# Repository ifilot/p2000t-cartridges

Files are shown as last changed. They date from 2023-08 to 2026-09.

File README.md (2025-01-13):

# P2000T Cartridges



## Purpose
Set of homebrew multirom cartridges for the P2000T. These cartridges contain
multiple ROM files stored on a single parallel EEPROM chip. The user can select
the desired program using a DIP switch. More information on these cartridges can
be found [on the website](https://www.philips-p2000t.nl/).

> [!TIP] 
> Have questions or comments about the **P2000T Cartridges**? Join
> the conversation and chat with the developers on our [Discord
> server](https://discord.gg/YtzJTWYAxy).

## MultiROM cartridges

> [!TIP]
> * Unsure which cartridge is right for you? The 32x16KiB THT SST39SF040 
>   (512 KiB ROM) offers the most features and is relatively straightforward to 
>   assemble with soldering.
> * When ordering the cartridges, it is advisable to choose an ENIG finish, 
>   opt for gold fingers, and specify a 30-degree chamfer on the edge connector.
> * For flashing the SST39SF0x0 chips, there is [a cheap Flasher tool](https://github.com/ifilot/pico-sst39sf0x0-programmer)
    available, based on the Raspberry Pi PICO.
> * A premade set of cartridge ROM-packs can be found [here](https://github.com/ifilot/p2000t-rompacks).

### 32x16KiB THT SST39SF040 (512 KiB ROM)

A SLOT1 cartridge designed to enable selection from 32 memory banks, assuming
the use of a 512KB ROM chip. It features a dedicated bracket PCB for holding the
DIP switch, which can be connected to the main PCB using either six wires or a
custom flex cable. Additionally, this cartridge includes a soft reset switch,
equipped with a debouncing circuit using a 74HC123 multivibrator. This cartridge
uses **THT** components.

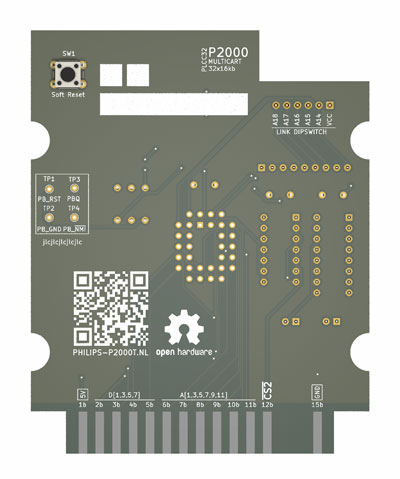
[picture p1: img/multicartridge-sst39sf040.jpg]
P2000T 32x16KiB THT SST39SF040 Cartridge


* [PCB - Multicartridge](multicartridge-tht-top-dipswitch/pcb)
* [PCB - DIP switch plate](multicartridge-tht-top-dipswitch/pcb/dipswitch-plate)
* [Flexcable](multicartridge-tht-top-dipswitch/pcb/flexconnector)
* [Casing (3d-print files)](multicartridge/case)

### 32x16KiB SMD SST39SF040 (512 KiB ROM)

Similar to the 32x16KiB THT SST39SF040 cartridge, this version utilizes **SMD**
components, with the exception of the PLCC32 THT socket used for the SST39SF040
chip. Design schematics for the DIP switch plate and the flexcable can be found
under the `THT` variant. Position and BOM files are provided for assembly
service.

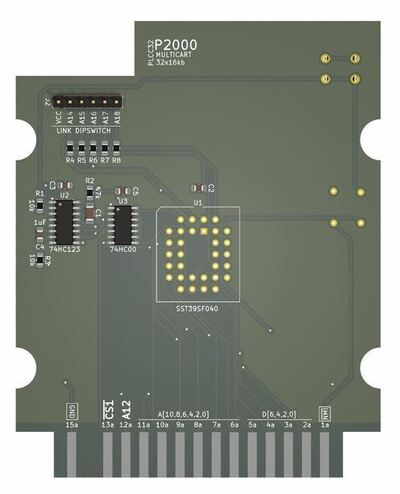
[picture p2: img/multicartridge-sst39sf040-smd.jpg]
P2000T 32x16KiB SMD SST39SF040 Cartridge


* [PCB - Multicartridge](multicartridge-smd-top-dipswitch/pcb)
* [PCB - DIP switch plate](multicartridge-tht-top-dipswitch/pcb/dipswitch-plate)
* [Flexcable](multicartridge-tht-top-dipswitch/pcb/flexconnector)
* [Casing (3d-print files)](multicartridge/case)

### 4 x 16KiB THT W27C512 (64 KiB ROM)

There is also a MultiROM cartridge featuring the reliable W27C512 chip, offering
4x16KB of storage. Unlike the 512KB version, this cartridge omits the soft reset
functionality as a cost-saving measure.

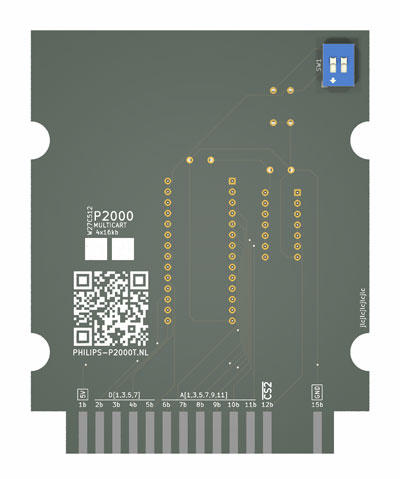
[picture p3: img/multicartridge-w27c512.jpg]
P2000T 4 x 16KiB THT W27C512 Cartridge


* [PCB - Multicartridge](multicartridge-w27c512/pcb)
* [Casing (3d-print files)](multicartridge-w27c512/case)

### Multirom cartridge - ZIF

SLOT1 cartridge that allows the user to select one of 32 banks (assuming a 512kb
ROM chip is used). Instead of a fixed ROM chip, this cartridge uses a ZIF socket
for easy exchange of the ROM chip. The cartridge also contains a soft reset
switch.

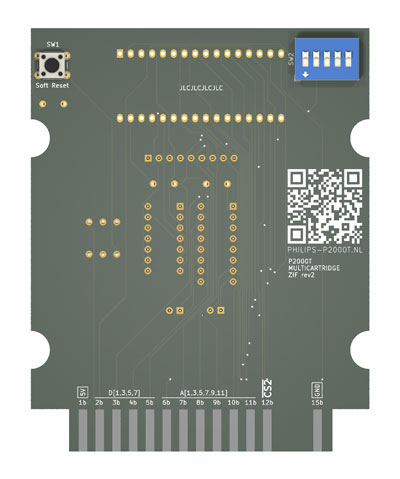
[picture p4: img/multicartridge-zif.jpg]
P2000T Multirom cartridge ZIF


* [PCB](multicartridge-zif/pcb/p2000t-multicartridge-zif)
* [Casing (3d-print files)](multicartridge-zif/case)

### MultiROM cartridge kit (smd)

Simplified version of the SST39SF040 / 512kb cartridge meant for easy soldering.
This cartridge assumes that the SMD components are already placed using an
assembly service of the PCB manufacturer.

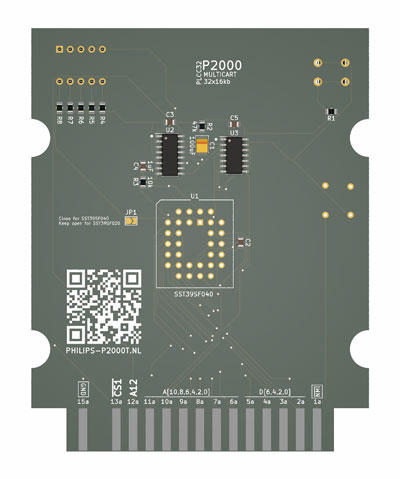
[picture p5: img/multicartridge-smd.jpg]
P2000T MultiROM cartridge kit


* [PCB](multicartridge-smd/pcb)
* [Casing (3d-print files)](multicartridge-smd/case)

## Enclosures

All enclosures have so-called mouse ears which helps in the adhesion
of the enclosure to the print plate. This prevents warping.

Recommended print settings for the enclosures:
* 0.4mm nozzle
* 0.20 - 0.25mm layer height
* 10%-20% infill

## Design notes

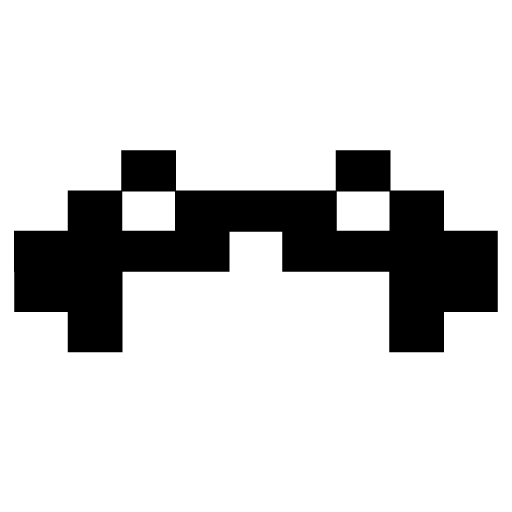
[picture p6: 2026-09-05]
multicartridge-sst39sf010-topbutton/img/fraxxon-goblin-shooter.png

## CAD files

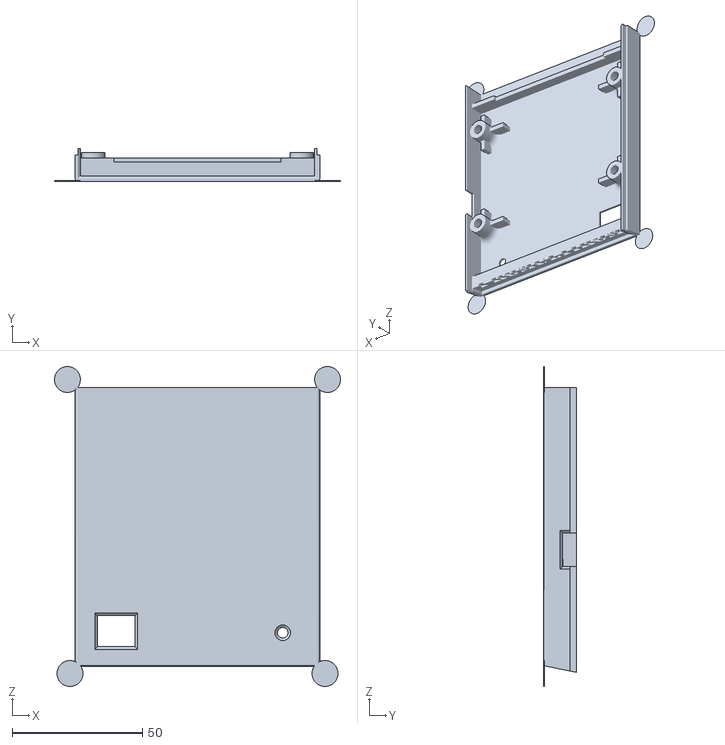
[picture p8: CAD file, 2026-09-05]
multicartridge-smd-32u4-front-dipswitch/case/multicolor/top.stl
110.0 x 12.5 x 123.0

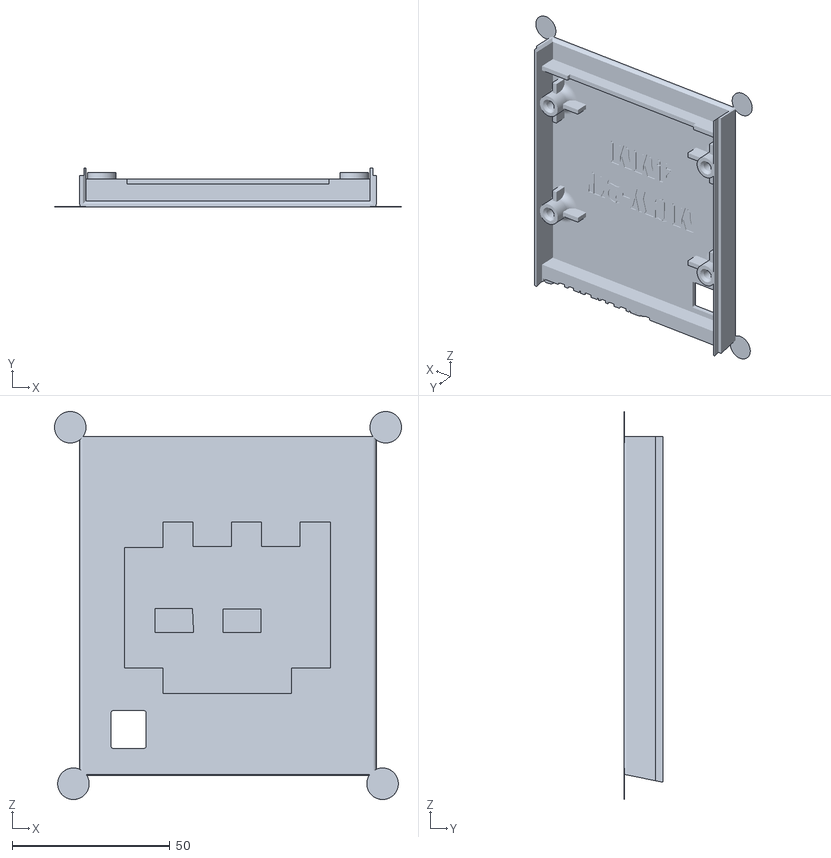
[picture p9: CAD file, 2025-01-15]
multicartridge-sst39sf010/cases/p2000t_gamecartridge_top.stl
110.0 x 12.5 x 123.0

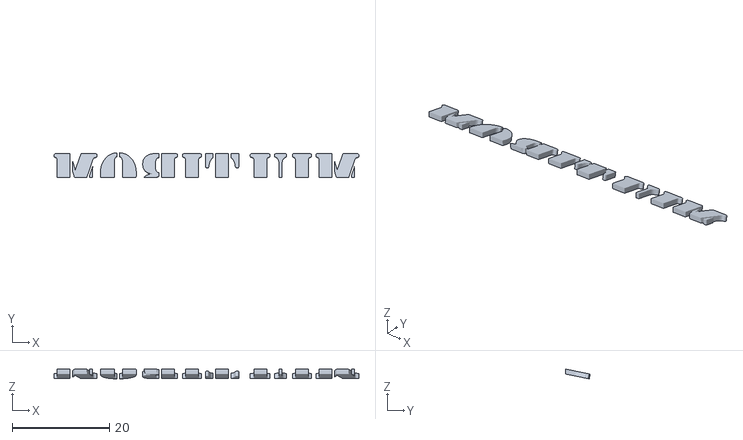
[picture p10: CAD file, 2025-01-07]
multicartridge-tht-top-dipswitch/case/multimaterial/p2000t_multicartridge-label-03-bottom.stl
62.6 x 5.04 x 2.01

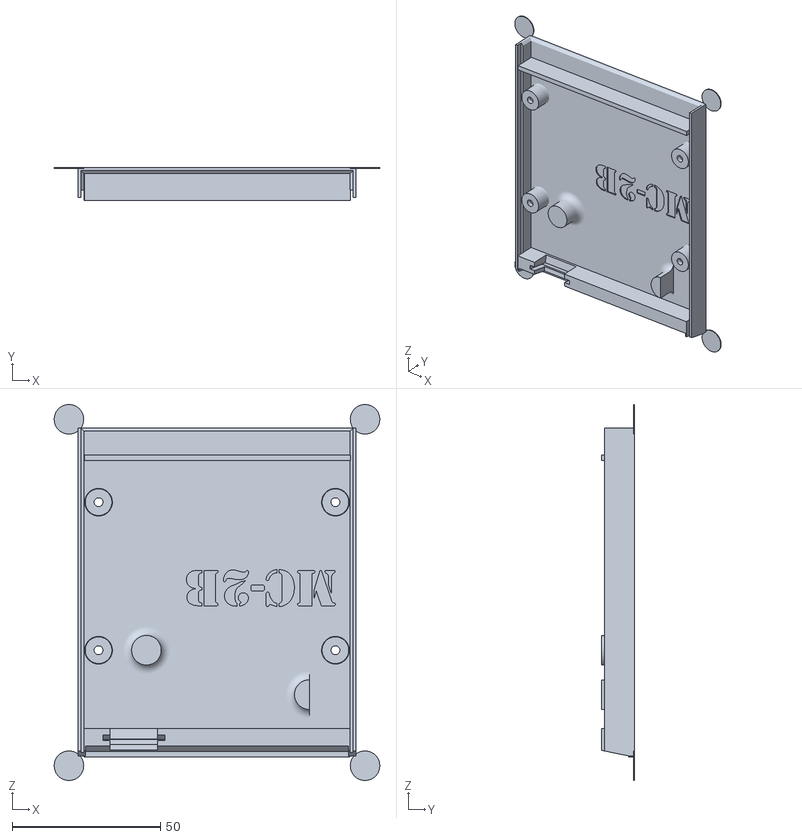
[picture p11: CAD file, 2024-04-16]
multicartridge-tht-top-dipswitch/case/p2000t_multicartridge_bottom.stl
110.0 x 11.0 x 127.0

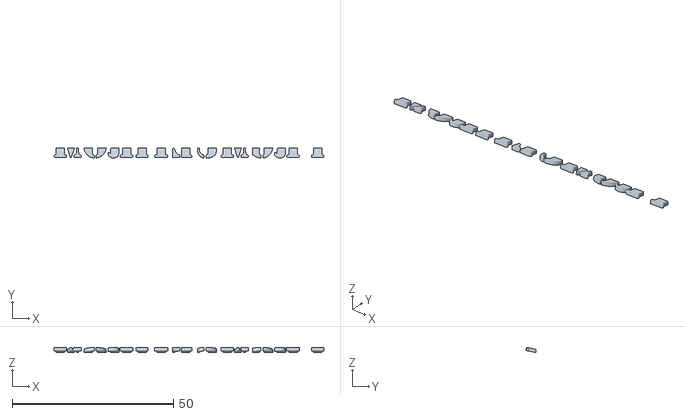
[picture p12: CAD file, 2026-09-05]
multicartridge-smd-32u4-front-dipswitch/case/multicolor/label-top.stl
83.7 x 3.14 x 1.62

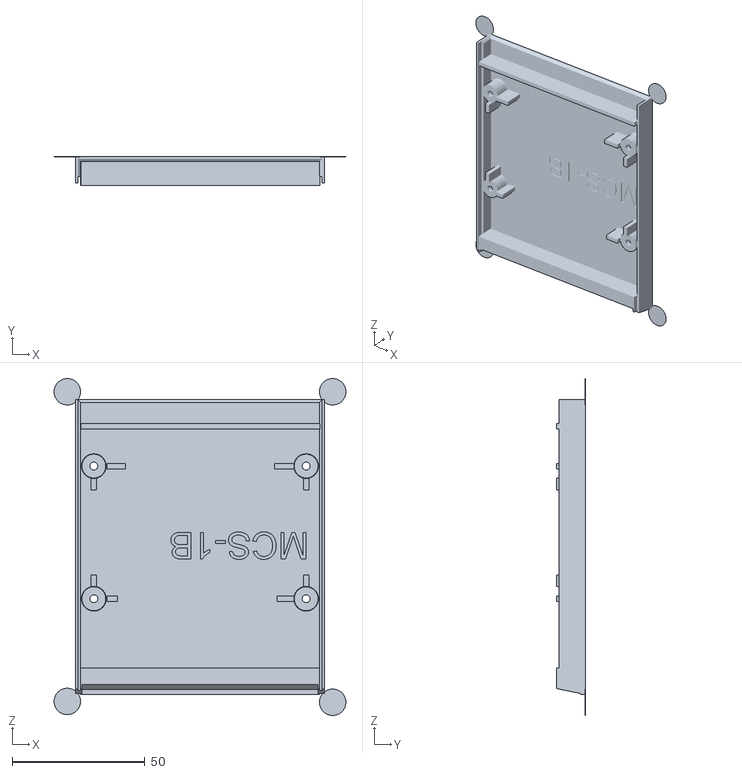
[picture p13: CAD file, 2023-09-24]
multicartridge-smd/cases/p2000t-smd-bottom.stl
110.0 x 11.0 x 127.0

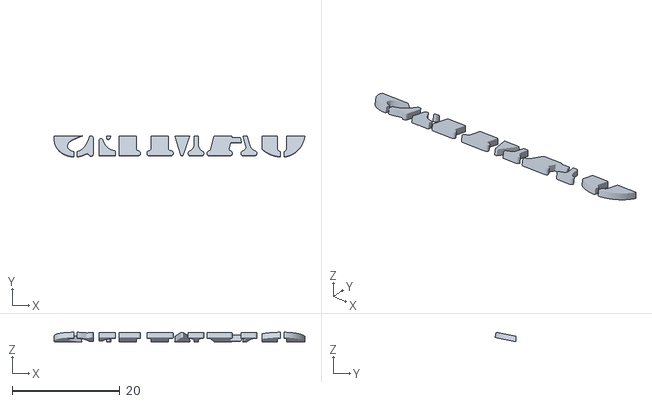
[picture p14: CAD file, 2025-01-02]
multicartridge-sst39sf010/cases/p2000t_gamecartridge_label_top.stl
46.6 x 3.93 x 1.78

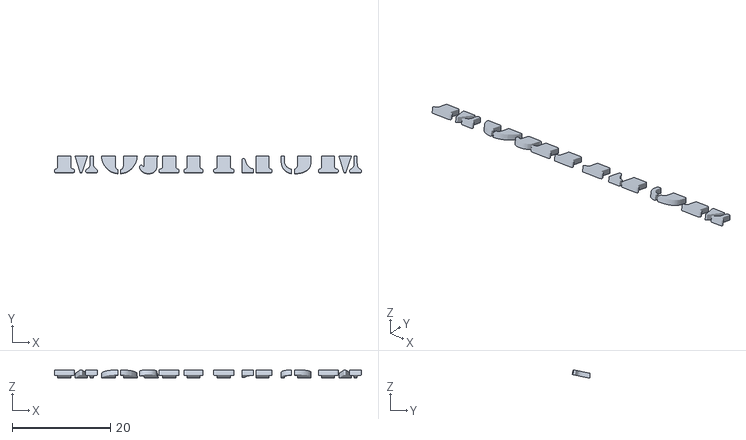
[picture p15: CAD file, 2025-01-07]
multicartridge-tht-top-dipswitch/case/multimaterial/p2000t_multicartridge-label-03-top.stl
62.5 x 3.62 x 1.72

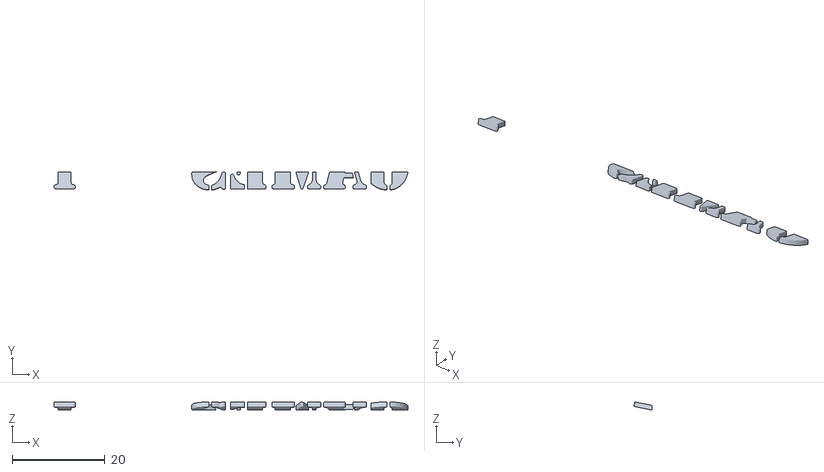
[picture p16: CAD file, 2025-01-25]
multicartridge-w27c512/cases/multimaterial/p2000t_gamecartridge_w27c512_label_top.stl
76.3 x 3.93 x 1.78

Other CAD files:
multicartridge-smd-32u4-front-dipswitch/case/top-bare.stl
multicartridge-smd/cases/p2000t-smd-top.stl
multicartridge-w27c512/cases/multicartridge_w27c512_bottom.stl
multicartridge-w27c512/cases/multimaterial/p2000t_gamecartridge_w27c512_top.stl
multicartridge-zif/case/p2000t_cartridge_zif_top_insert_38.stl
multicartridge-smd-32u4-front-dipswitch/case/bottom-bare.stl
multicartridge-tht-top-dipswitch/case/p2000t_multicartridge_top.stl
multicartridge-w27c512/cases/multicartridge_w27c512_top_4mm_inserts.stl
multicartridge-zif/case/p2000t_cartridge_zif_top.stl
multicartridge-smd-32u4-front-dipswitch/case/multicolor/bottom.stl
multicartridge-smd-32u4-front-dipswitch/case/multicolor/label-bottom.stl
multicartridge-sst39sf010/cases/p2000t_gamecartridge_bottom.stl
multicartridge-sst39sf010/cases/p2000t_gamecartridge_ghost.stl
multicartridge-sst39sf010/cases/p2000t_gamecartridge_label_bottom.stl
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

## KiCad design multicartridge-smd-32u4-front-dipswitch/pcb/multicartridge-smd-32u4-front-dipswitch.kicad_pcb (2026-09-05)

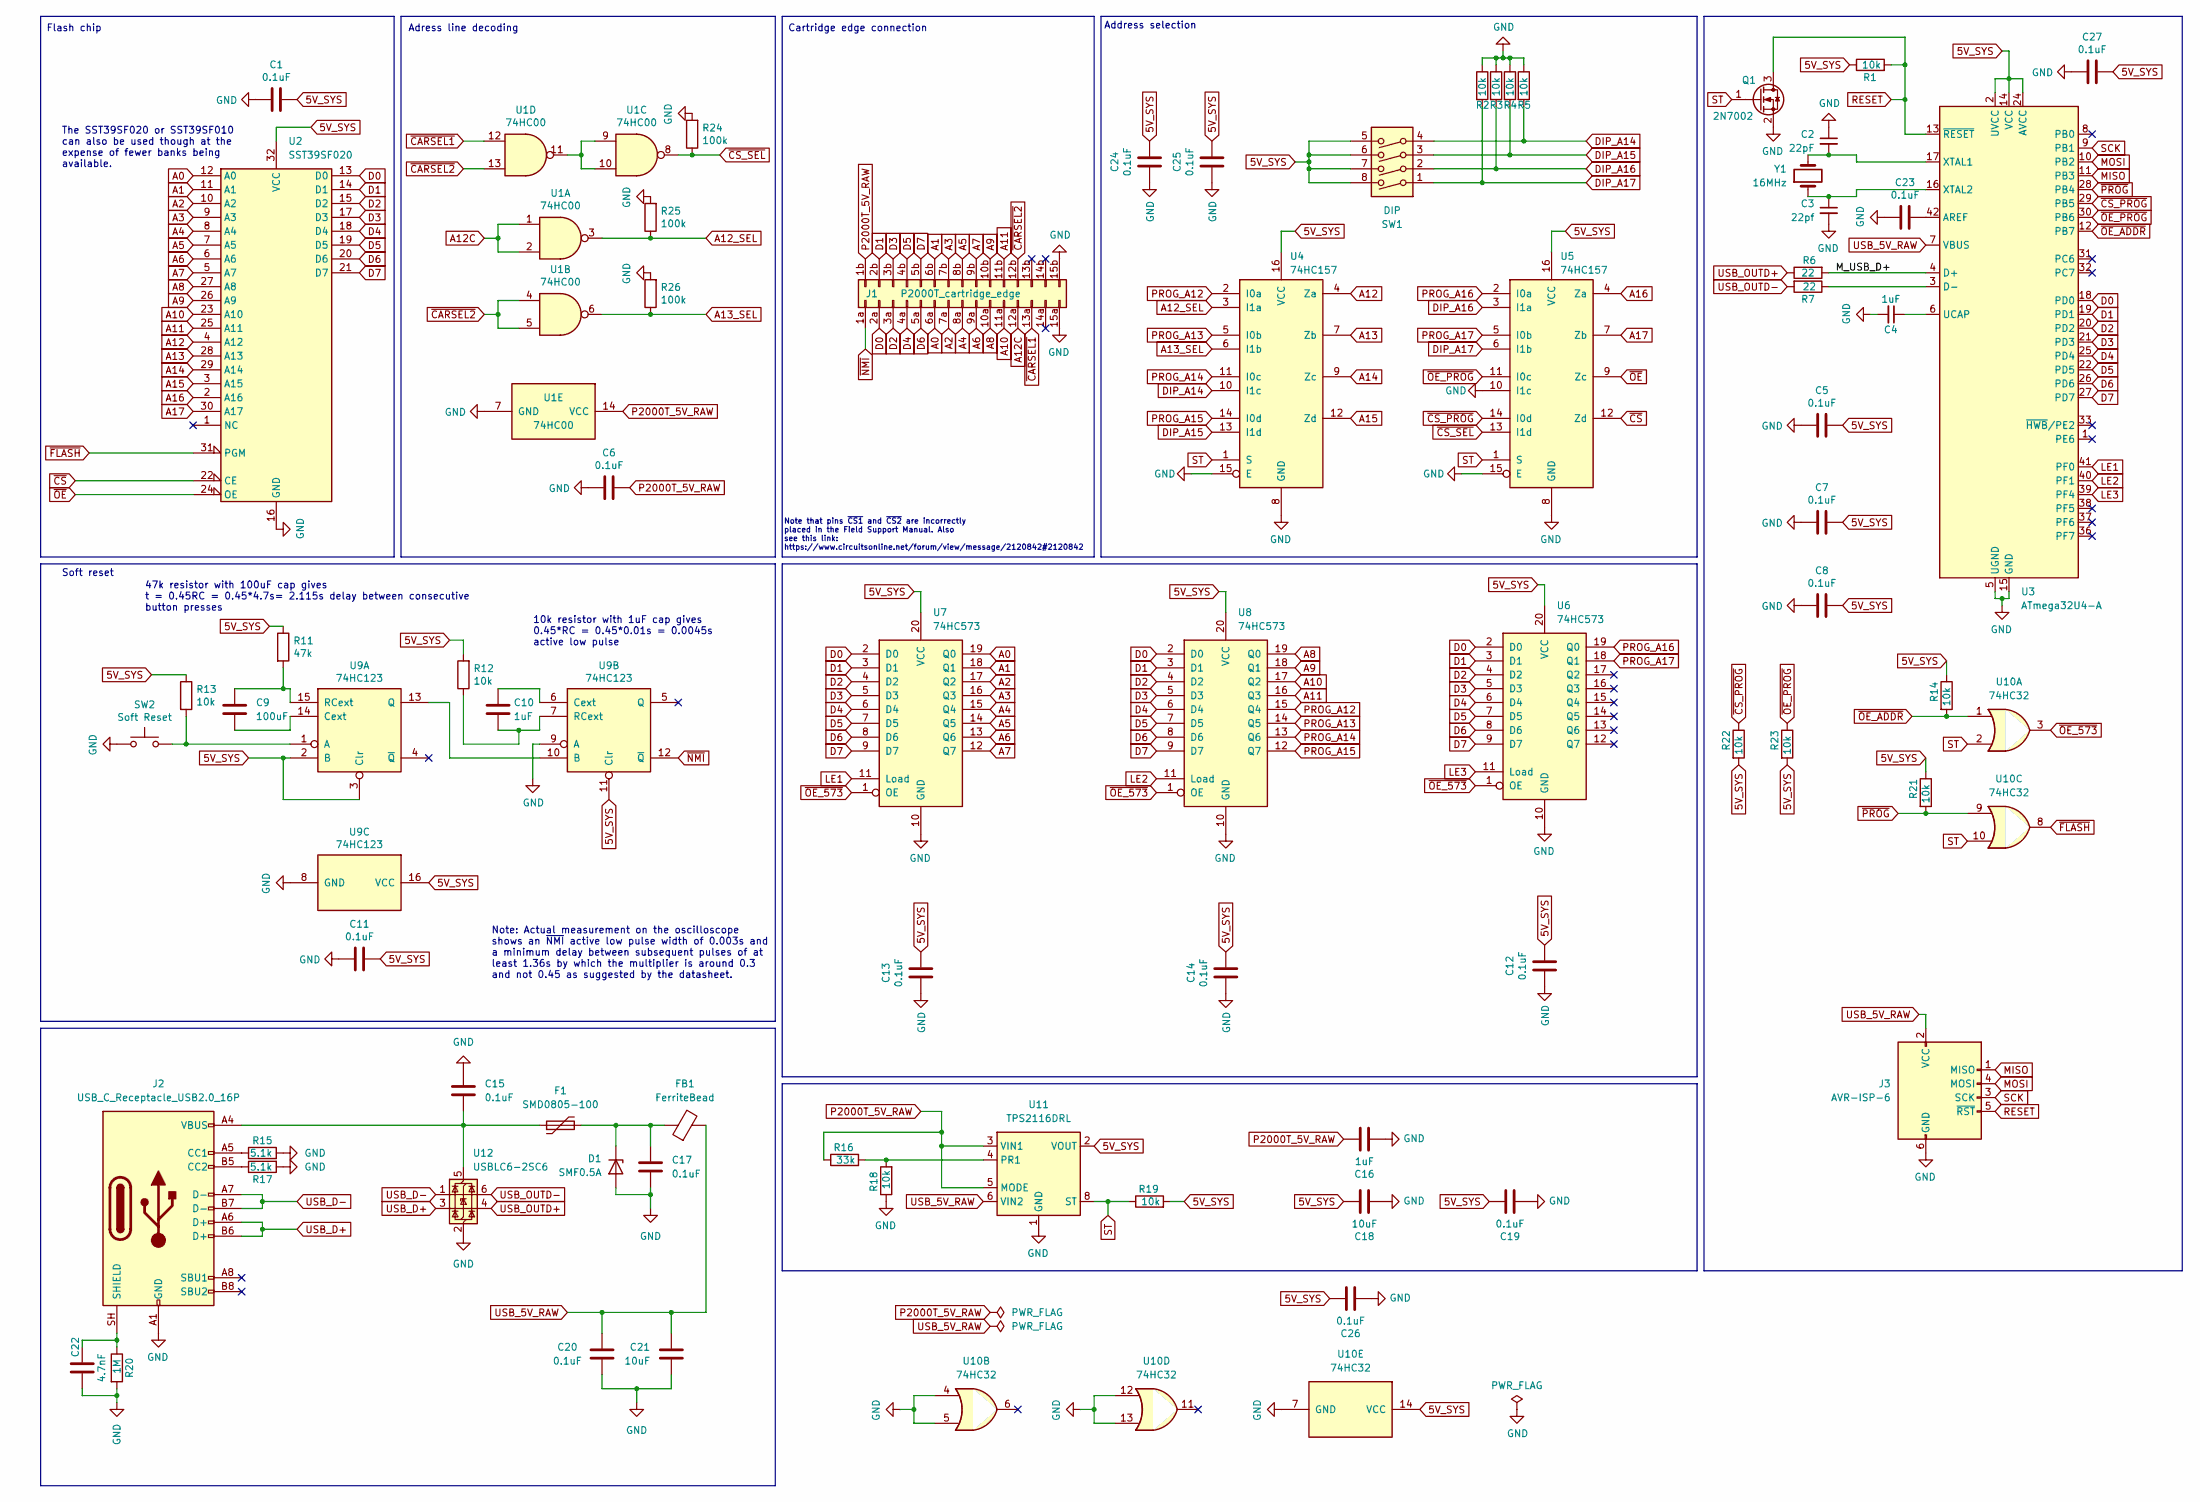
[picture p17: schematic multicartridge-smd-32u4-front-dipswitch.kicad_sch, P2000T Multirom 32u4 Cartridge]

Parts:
C1, C5, C6, C7, C8, C11, C12, C13, C14, C15, C17, C19, C20, C23, C24, C25, C26, C27: 0.1uF; C_0805_2012Metric; LCSC C28233
C2: 22pF; C_0805_2012Metric; LCSC C1804
C3: 22pf; C_0805_2012Metric; LCSC C1804
C4, C10, C16: 1uF; C_0805_2012Metric; LCSC C28323
C9: 100uF; C_1206_3216Metric; LCSC C15008
C18, C21: 10uF; C_0805_2012Metric; LCSC C15850
C22: 4.7nF; C_0805_2012Metric; LCSC C1744
D1: SMF0.5A; D_SOD-123F; LCSC C20883113
F1: SMD0805-100; Fuse_0805_2012Metric; LCSC C22435710
FB1: FerriteBead; R_0805_2012Metric; LCSC C1015
J1: P2000T_cartridge_edge; p2000t_cartridge_edge
J2: USB_C_Receptacle_USB2.0_16P; USB_C_Receptacle_HRO_TYPE-C-31-M-12
J3: AVR-ISP-6; IDC-Header_2x03_P2.54mm_Vertical
Q1: 2N7002; SOT-23; LCSC C8545
R1, R2, R3, R4, R5, R12, R13, R14, R18, R19, R21, R22, R23: 10k; C_0805_2012Metric; LCSC C17414
R6, R7: 22; R_0805_2012Metric; LCSC C17561
R11: 47k; C_0805_2012Metric; LCSC C17713
R15, R17: 5.1k; R_0805_2012Metric; LCSC C27834
R16: 33k; C_0805_2012Metric; LCSC C17633
R20: 1M; R_0805_2012Metric; LCSC C27834
R24, R25, R26: 100k; C_0805_2012Metric; LCSC C17514
SW1: DIP; SW_DIP_SPSTx04_Slide_9.78x12.34mm_W7.62mm_P2.54mm
SW2: Soft Reset; SW_PUSH_6mm
U1: 74HC00; SOIC-14_3.9x8.7mm_P1.27mm; LCSC C5586
U2: SST39SF020; PLCC-32_THT-Socket
U3: ATmega32U4-A; TQFP-44_10x10mm_P0.8mm; LCSC C44854
U4, U5: 74HC157; SOIC-16_3.9x9.9mm_P1.27mm; LCSC C5609
U6, U7, U8: 74HC573; SOIC-20W_7.5x12.8mm_P1.27mm; LCSC C5608
U9: 74HC123; SOIC-16_3.9x9.9mm_P1.27mm; LCSC C5597
U10: 74HC32; SOIC-14_3.9x8.7mm_P1.27mm; LCSC C5632
U11: TPS2116DRL; SOT-583-8; LCSC C3235557
U12: USBLC6-2SC6; SOT-23-6; LCSC C2687116
Y1: 16MHz; Crystal_HC49-U_Vertical

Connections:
5V_SYS: C1.1, C5.1, C7.1, C8.1, C11.1, C12.1, C13.1, C14.1, C18.1, C19.1, C24.1, C25.1, C26.1, C27.1, R1.1, R11.1, R12.2, R13.1, R14.1, R19.2, R21.1, R22.2, R23.2, SW1.5, SW1.6, SW1.7, SW1.8, U2.32 (VCC), U3.2 (UVCC), U3.14 (VCC), U3.24 (AVCC), U3.34 (VCC), U3.44 (AVCC), U4.16 (VCC), U5.16 (VCC), U6.20 (VCC), U7.20 (VCC), U8.20 (VCC), U9.2 (B), U9.3 (Clr), U9.11 (Clr), U9.16 (VCC), U10.14 (VCC), U11.2 (VOUT), U11.7 (VOUT)
/M_USB_D+: R6.2, U3.4 (D+)
A0: J1.6a, U2.12 (A0), U7.19 (Q0)
A1: J1.6b, U2.11 (A1), U7.18 (Q1)
A2: J1.7a, U2.10 (A2), U7.17 (Q2)
A3: J1.7b, U2.9 (A3), U7.16 (Q3)
A4: J1.8a, U2.8 (A4), U7.15 (Q4)
A5: J1.8b, U2.7 (A5), U7.14 (Q5)
A6: J1.9a, U2.6 (A6), U7.13 (Q6)
A7: J1.9b, U2.5 (A7), U7.12 (Q7)
A8: J1.10a, U2.27 (A8), U8.19 (Q0)
A9: J1.10b, U2.26 (A9), U8.18 (Q1)
A10: J1.11a, U2.23 (A10), U8.17 (Q2)
A11: J1.11b, U2.25 (A11), U8.16 (Q3)
A12: U2.4 (A12), U4.4 (Za)
A12C: J1.12a, U1.1, U1.2
A12_SEL: R25.1, U1.3, U4.3 (I1a)
A13: U2.28 (A13), U4.7 (Zb)
A13_SEL: R26.1, U1.6, U4.6 (I1b)
A14: U2.29 (A14), U4.9 (Zc)
A15: U2.3 (A15), U4.12 (Zd)
A16: U2.2 (A16), U5.4 (Za)
A17: U2.30 (A17), U5.7 (Zb)
D0: J1.2a, U2.13 (D0), U3.18 (PD0), U6.2 (D0), U7.2 (D0), U8.2 (D0)
D1: J1.2b, U2.14 (D1), U3.19 (PD1), U6.3 (D1), U7.3 (D1), U8.3 (D1)
D2: J1.3a, U2.15 (D2), U3.20 (PD2), U6.4 (D2), U7.4 (D2), U8.4 (D2)
D3: J1.3b, U2.17 (D3), U3.21 (PD3), U6.5 (D3), U7.5 (D3), U8.5 (D3)
D4: J1.4a, U2.18 (D4), U3.25 (PD4), U6.6 (D4), U7.6 (D4), U8.6 (D4)
D5: J1.4b, U2.19 (D5), U3.22 (PD5), U6.7 (D5), U7.7 (D5), U8.7 (D5)
D6: J1.5a, U2.20 (D6), U3.26 (PD6), U6.8 (D6), U7.8 (D6), U8.8 (D6)
D7: J1.5b, U2.21 (D7), U3.27 (PD7), U6.9 (D7), U7.9 (D7), U8.9 (D7)
DIP_A14: R5.2, SW1.4, U4.10 (I1c)
DIP_A15: R4.2, SW1.3, U4.13 (I1d)
DIP_A16: R3.2, SW1.2, U5.3 (I1a)
DIP_A17: R2.2, SW1.1, U5.6 (I1b)
GND: C1.2, C2.1, C3.2, C4.2, C5.2, C6.2, C7.2, C8.2, C11.2, C12.2, C13.2, C14.2, C15.1, C16.2, C17.2, C18.2, C19.2, C20.2, C21.1, C22.2, C23.2, C24.2, C25.2, C26.2, C27.2, D1.2 (A), J1.15a, J1.15b, J2.A1 (GND), J2.A12 (GND), J2.B1 (GND), J2.B12 (GND), J3.6 (GND), Q1.2 (S), R2.1, R3.1, R4.1, R5.1, R15.2, R17.2, R18.1, R20.2, R24.2, R25.2, R26.2, SW2.1, U1.7 (GND), U2.16 (GND), U3.5 (UGND), U3.15 (GND), U3.23 (GND), U3.35 (GND), U3.43 (GND), U4.8 (GND), U4.15 (E), U5.8 (GND), U5.10 (I1c), U5.15 (E), U6.10 (GND), U7.10 (GND), U8.10 (GND), U9.8 (GND), U9.9 (A), U10.4, U10.5, U10.7 (GND), U10.12, U10.13, U11.1 (GND), U12.2 (GND)
LE1: U3.41 (PF0), U7.11 (Load)
LE2: U3.40 (PF1), U8.11 (Load)
LE3: U3.39 (PF4), U6.11 (Load)
MISO: J3.1 (MISO), U3.11 (PB3)
MOSI: J3.4 (MOSI), U3.10 (PB2)
unnamed: C17.1, D1.1 (K), F1.2, FB1.1
unnamed: J2.A5 (CC1), R15.1
unnamed: J2.B5 (CC2), R17.1
unnamed: C22.1, J2.SH (SHIELD), R20.1
unnamed: U1.9, U1.10, U1.11
unnamed: C23.1, U3.42 (AREF)
unnamed: R7.1, U3.3 (D-)
unnamed: C4.1, U3.6 (UCAP)
unnamed: C2.2, U3.17 (XTAL1), Y1.2
unnamed: C3.1, U3.16 (XTAL2), Y1.1
unnamed: R13.2, SW2.2, U9.1 (A)
unnamed: C9.2, U9.14 (Cext)
unnamed: U9.10 (B), U9.13 (Q)
unnamed: C9.1, R11.2, U9.15 (RCext)
unnamed: C10.1, U9.6 (Cext)
unnamed: C10.2, R12.1, U9.7 (RCext)
unnamed: R16.2, R18.2, U11.4 (PR1)
unnamed: C15.2, F1.1, J2.A4 (VBUS), J2.A9 (VBUS), J2.B4 (VBUS), J2.B9 (VBUS), U12.5 (VBUS)
P2000T_5V_RAW: C6.1, C16.1, J1.1b, R16.1, U1.14 (VCC), U11.3 (VIN1), U11.5 (MODE)
PROG_A12: U4.2 (I0a), U8.15 (Q4)
PROG_A13: U4.5 (I0b), U8.14 (Q5)
PROG_A14: U4.11 (I0c), U8.13 (Q6)
PROG_A15: U4.14 (I0d), U8.12 (Q7)
PROG_A16: U5.2 (I0a), U6.19 (Q0)
PROG_A17: U5.5 (I0b), U6.18 (Q1)
RESET: J3.5 (~RST), Q1.3 (D), R1.2, U3.13 (~RESET)
SCK: J3.3 (SCK), U3.9 (PB1)
ST: Q1.1 (G), R19.1, U4.1 (S), U5.1 (S), U10.2, U10.10, U11.8 (ST)
USB_5V_RAW: C20.1, C21.2, FB1.2, J3.2 (VCC), U3.7 (VBUS), U11.6 (VIN2)
USB_D+: J2.A6 (D+), J2.B6 (D+), U12.3 (I/O2)
USB_D-: J2.A7 (D-), J2.B7 (D-), U12.1 (I/O1)
USB_OUTD+: R6.1, U12.4 (I/O2)
USB_OUTD-: R7.2, U12.6 (I/O1)
~CARSEL1: J1.13a, U1.12
~CARSEL2: J1.12b, U1.4, U1.5, U1.13
~CS_PROG: R22.1, U3.29 (PB5), U5.14 (I0d)
~CS_SEL: R24.1, U1.8, U5.13 (I1d)
~CS: U2.22 (CE), U5.12 (Zd)
~FLASH: U2.31 (PGM), U10.8
~NMI: J1.1a, U9.12 (~Q)
~OE_573: U6.1 (OE), U7.1 (OE), U8.1 (OE), U10.3
~OE_ADDR: R14.2, U3.12 (PB7), U10.1
~OE_PROG: R23.1, U3.30 (PB6), U5.11 (I0c)
~OE: U2.24 (OE), U5.9 (Zc)
~PROG: R21.2, U3.28 (PB4), U10.9

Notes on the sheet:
Note that pins ~{CS1} and ~{CS2} are incorrectly placed in the Field Support Manual. Also see this link: https://www.circuitsonline.net/forum/view/message/2120842#2120842
Note: Actual measurement on the oscilloscope shows an ~{NMI} active low pulse width of 0.003s and a minimum delay between subsequent pulses of at least 1.36s by which the multiplier is around 0.3 and not 0.45 as suggested by the datasheet.
Cartridge edge connection
Flash chip
Adress line decoding
The SST39SF020 or SST39SF010 can also be used though at the expense of fewer banks being available.
Soft reset
47k resistor with 100uF cap gives t = 0.45RC = 0.45*4.7s= 2.115s delay between consecutive button presses
10k resistor with 1uF cap gives 0.45*RC = 0.45*0.01s = 0.0045s active low pulse
Address selection

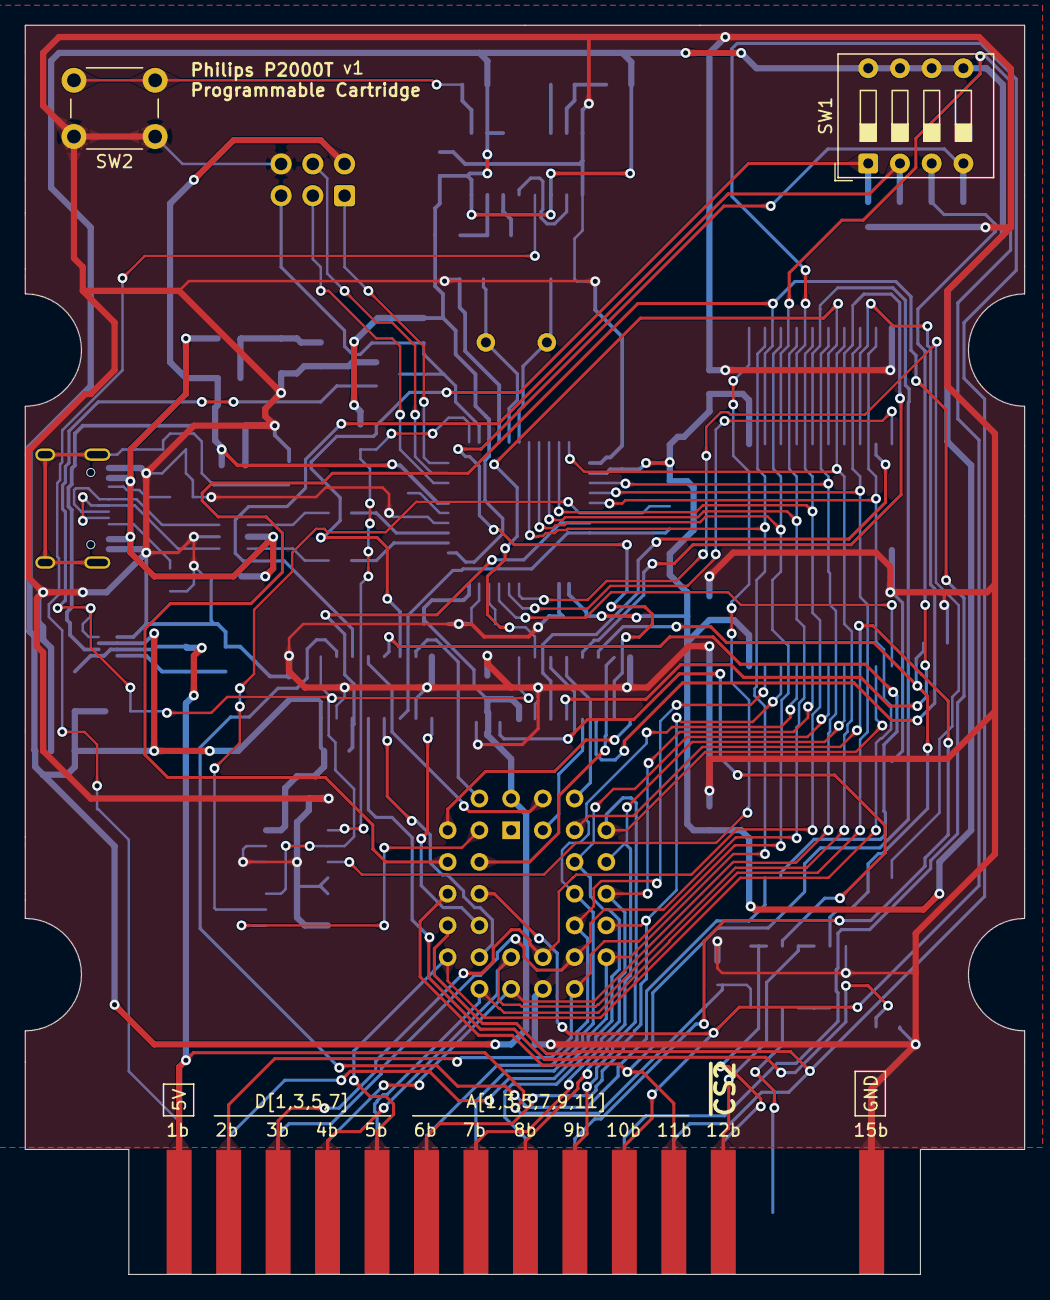
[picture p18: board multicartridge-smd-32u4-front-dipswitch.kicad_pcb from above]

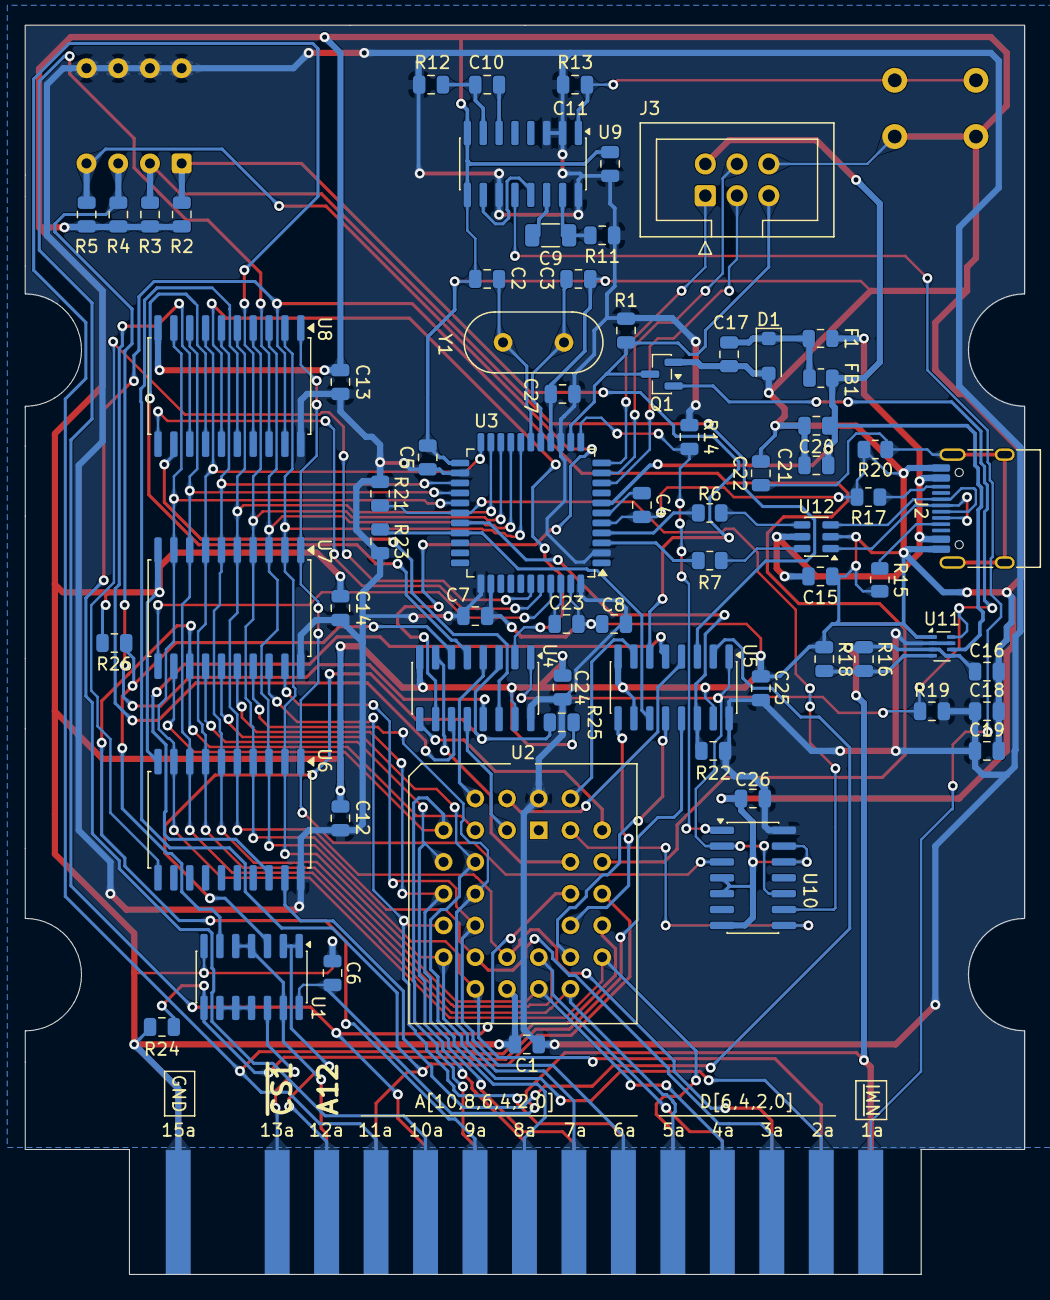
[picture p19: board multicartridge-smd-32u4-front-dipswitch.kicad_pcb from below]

Board: 2 copper layers, 80.0 x 100.0 mm, 72 parts (70 on the bottom side), 86 nets.

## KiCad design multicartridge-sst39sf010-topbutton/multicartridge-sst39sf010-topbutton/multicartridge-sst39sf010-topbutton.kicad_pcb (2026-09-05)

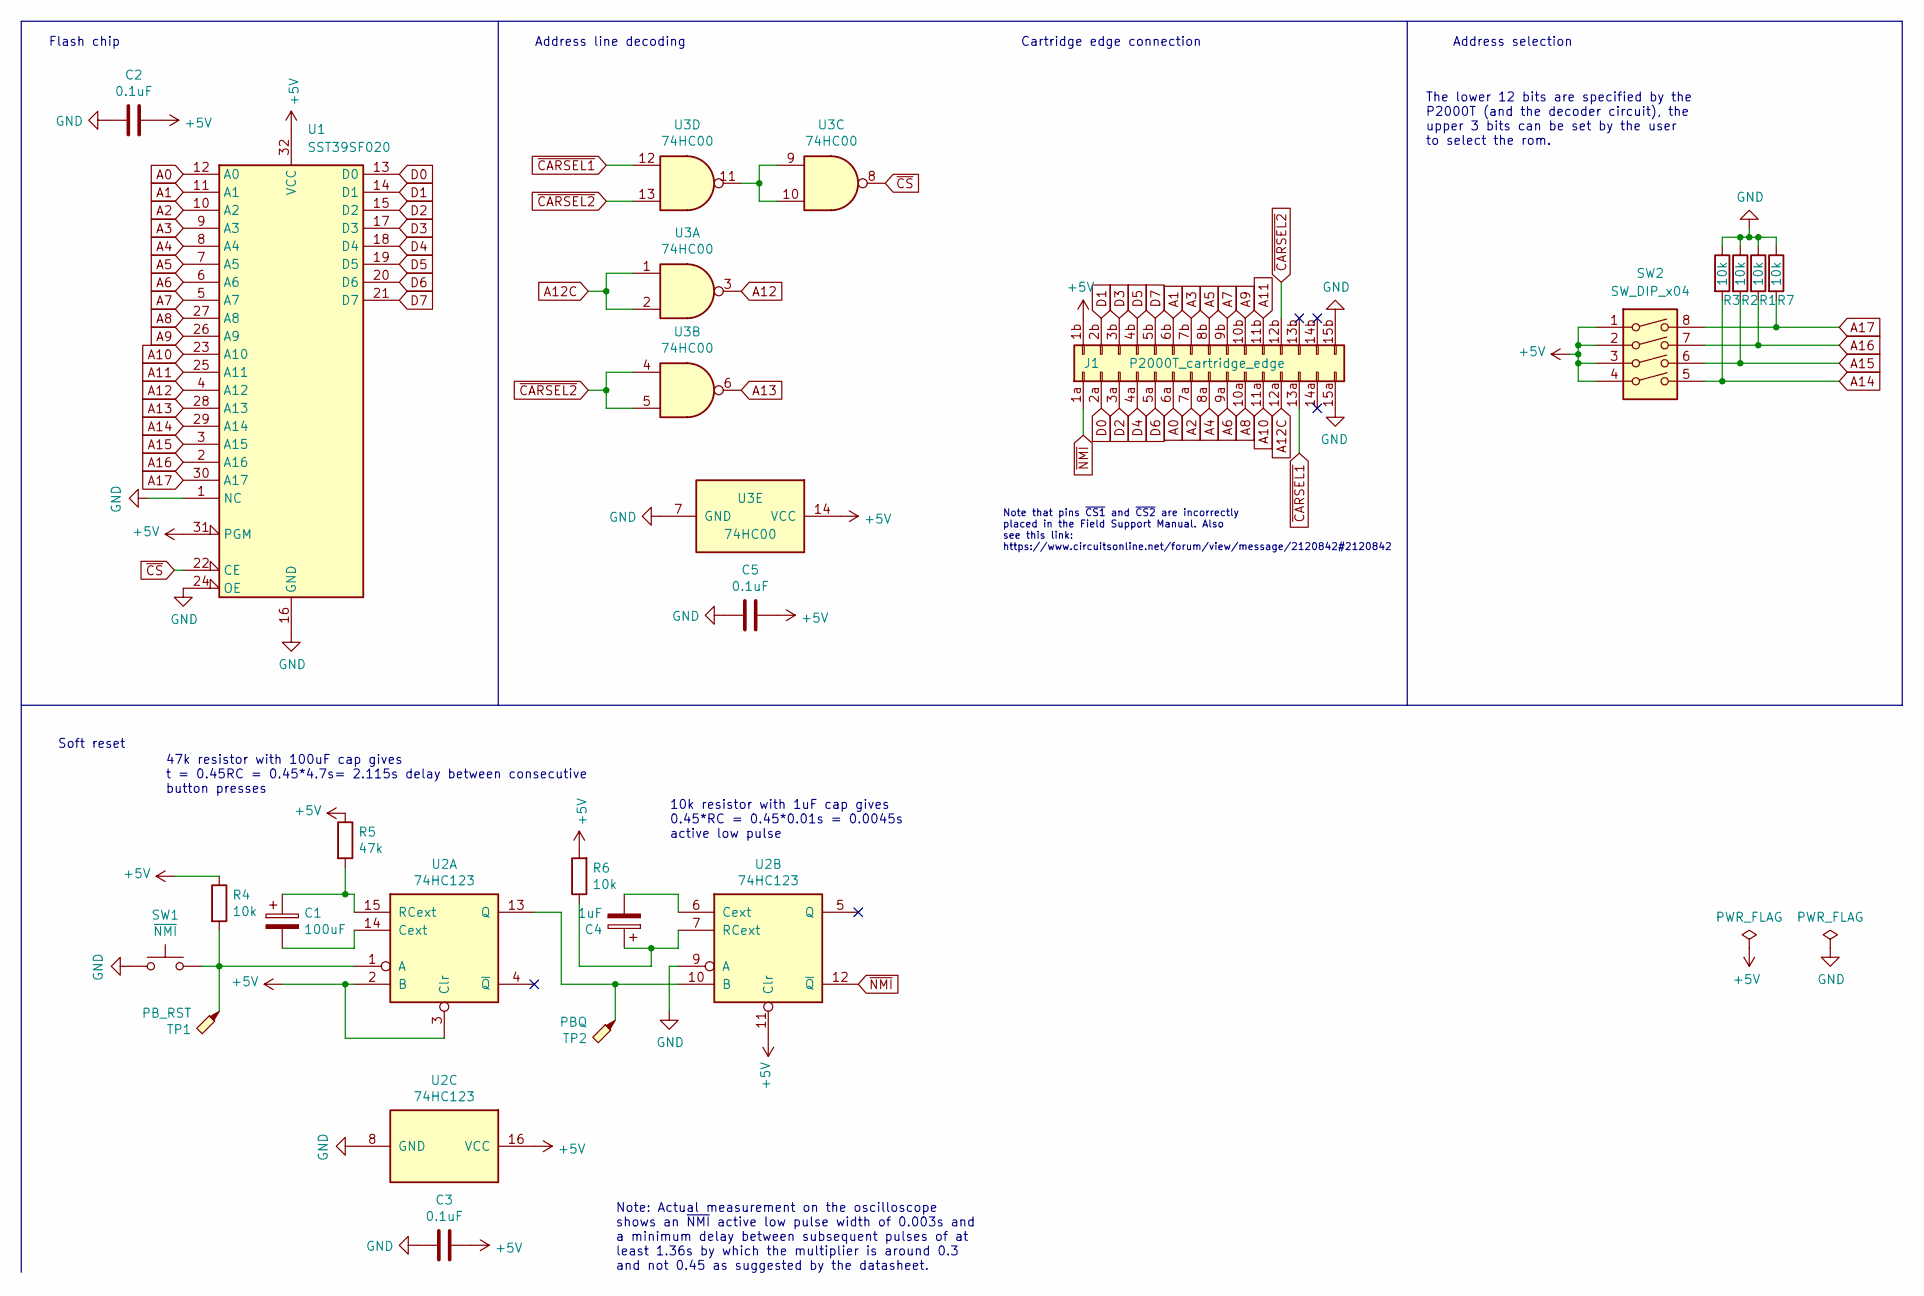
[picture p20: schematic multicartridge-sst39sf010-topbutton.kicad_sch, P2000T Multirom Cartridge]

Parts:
C1: 100uF; CP_Radial_D6.3mm_P2.50mm
C2, C3, C5: 0.1uF; C_Disc_D5.0mm_W2.5mm_P5.00mm
C4: 1uF; CP_Radial_D6.3mm_P2.50mm
J1: P2000T_cartridge_edge; p2000t_cartridge_edge
R1, R2, R3, R4, R6, R7: 10k; R_Axial_DIN0207_L6.3mm_D2.5mm_P7.62mm_Horizontal
R5: 47k; R_Axial_DIN0207_L6.3mm_D2.5mm_P7.62mm_Horizontal
SW1: ~{NMI}; SW_Tactile_SKHH_Angled
SW2: SW_DIP_x04; SW_DIP_SPSTx04_Slide_9.78x12.34mm_W7.62mm_P2.54mm
TP1: PB_RST; TestPoint_THTPad_D1.5mm_Drill0.7mm
TP2: PBQ; TestPoint_THTPad_D1.5mm_Drill0.7mm
U1: SST39SF020; PLCC-32_THT-Socket
U2: 74HC123; DIP-16_W7.62mm_Socket
U3: 74HC00; DIP-14_W7.62mm_Socket

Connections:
+5V: C2.1, C3.1, C5.1, J1.1b, R4.1, R5.1, R6.2, SW2.1, SW2.2, SW2.3, SW2.4, U1.31 (PGM), U1.32 (VCC), U2.2 (B), U2.3 (Clr), U2.11 (Clr), U2.16 (VCC), U3.14 (VCC)
A0: J1.6a, U1.12 (A0)
A1: J1.6b, U1.11 (A1)
A2: J1.7a, U1.10 (A2)
A3: J1.7b, U1.9 (A3)
A4: J1.8a, U1.8 (A4)
A5: J1.8b, U1.7 (A5)
A6: J1.9a, U1.6 (A6)
A7: J1.9b, U1.5 (A7)
A8: J1.10a, U1.27 (A8)
A9: J1.10b, U1.26 (A9)
A10: J1.11a, U1.23 (A10)
A11: J1.11b, U1.25 (A11)
A12: U1.4 (A12), U3.3
A12C: J1.12a, U3.1, U3.2
A13: U1.28 (A13), U3.6
A14: R3.2, SW2.5, U1.29 (A14)
A15: R2.2, SW2.6, U1.3 (A15)
A16: R1.2, SW2.7, U1.2 (A16)
A17: R7.2, SW2.8, U1.30 (A17)
D0: J1.2a, U1.13 (D0)
D1: J1.2b, U1.14 (D1)
D2: J1.3a, U1.15 (D2)
D3: J1.3b, U1.17 (D3)
D4: J1.4a, U1.18 (D4)
D5: J1.4b, U1.19 (D5)
D6: J1.5a, U1.20 (D6)
D7: J1.5b, U1.21 (D7)
GND: C2.2, C3.2, C5.2, J1.15a, J1.15b, R1.1, R2.1, R3.1, R7.1, SW1.1, U1.1 (NC), U1.16 (GND), U1.24 (OE), U2.8 (GND), U2.9 (A), U3.7 (GND)
unnamed: R4.2, SW1.2, TP1.1, U2.1 (A)
unnamed: C1.2, U2.14 (Cext)
unnamed: TP2.1, U2.10 (B), U2.13 (Q)
unnamed: C1.1, R5.2, U2.15 (RCext)
unnamed: C4.2, U2.6 (Cext)
unnamed: C4.1, R6.1, U2.7 (RCext)
unnamed: U3.9, U3.10, U3.11
~CARSEL1: J1.13a, U3.12
~CARSEL2: J1.12b, U3.4, U3.5, U3.13
~CS: U1.22 (CE), U3.8
~NMI: J1.1a, U2.12 (~Q)

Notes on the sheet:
Soft reset
Note that pins ~{CS1} and ~{CS2} are incorrectly placed in the Field Support Manual. Also see this link: https://www.circuitsonline.net/forum/view/message/2120842#2120842
Cartridge edge connection
Flash chip
Address line decoding
Note: Actual measurement on the oscilloscope shows an ~{NMI} active low pulse width of 0.003s and a minimum delay between subsequent pulses of at least 1.36s by which the multiplier is around 0.3 and not 0.45 as suggested by the datasheet.
47k resistor with 100uF cap gives t = 0.45RC = 0.45*4.7s= 2.115s delay between consecutive button presses
10k resistor with 1uF cap gives 0.45*RC = 0.45*0.01s = 0.0045s active low pulse
The lower 12 bits are specified by the P2000T (and the decoder circuit), the upper 3 bits can be set by the user to select the rom.
Address selection

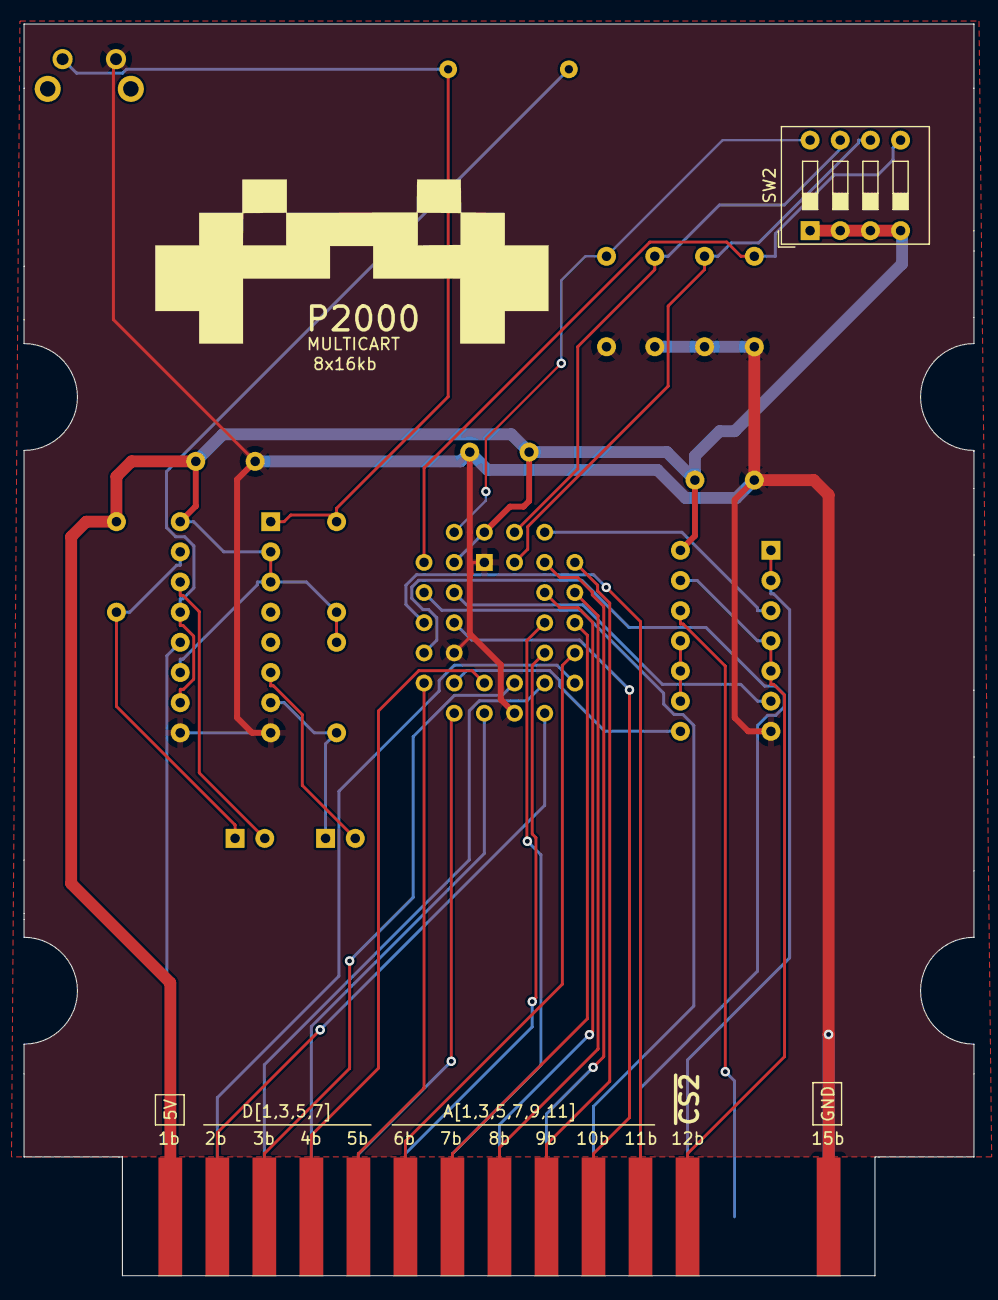
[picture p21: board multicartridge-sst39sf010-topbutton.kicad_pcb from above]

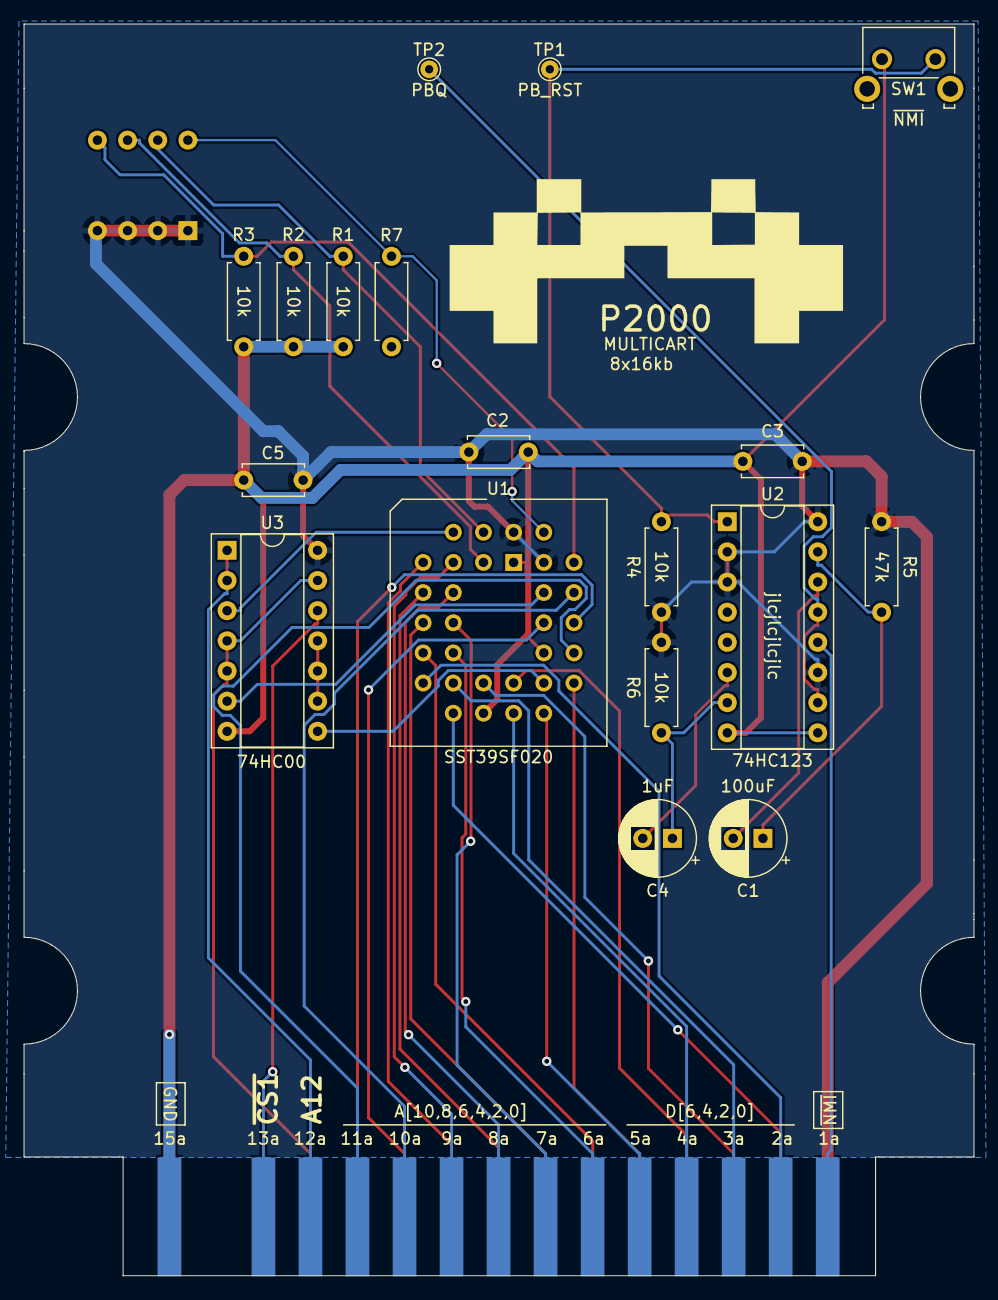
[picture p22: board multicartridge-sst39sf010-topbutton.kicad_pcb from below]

Board: 2 copper layers, 80.0 x 105.4 mm, 22 parts (20 on the bottom side), 40 nets.

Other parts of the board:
G001, G002: LOGO; fraxxon_goblin_shooter

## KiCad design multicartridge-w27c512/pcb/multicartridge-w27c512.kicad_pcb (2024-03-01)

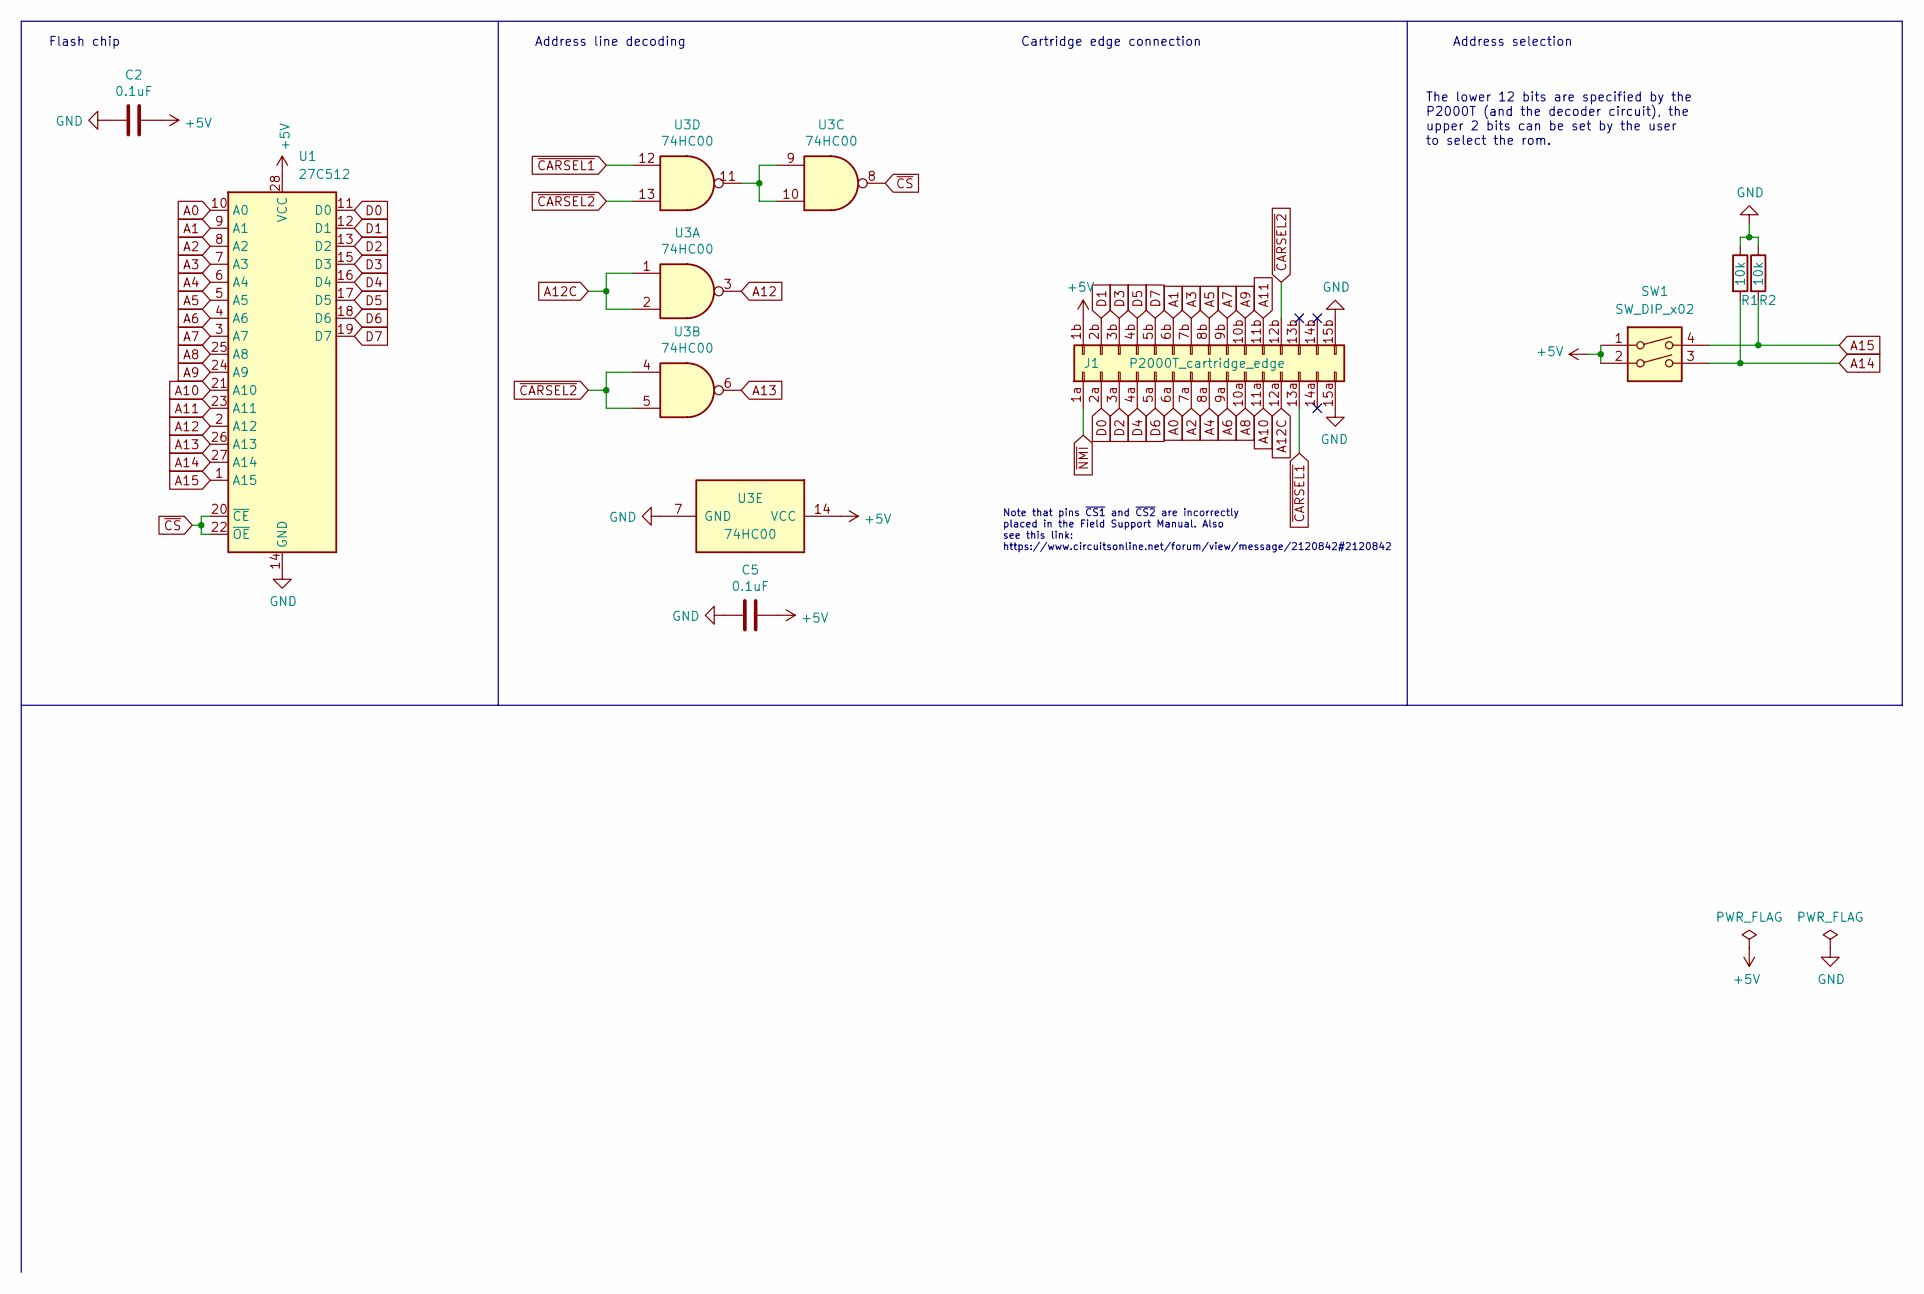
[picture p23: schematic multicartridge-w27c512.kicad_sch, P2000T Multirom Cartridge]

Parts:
C2, C5: 0.1uF; C_Disc_D5.0mm_W2.5mm_P5.00mm
J1: P2000T_cartridge_edge; p2000t_cartridge_edge
R1, R2: 10k; R_Axial_DIN0207_L6.3mm_D2.5mm_P7.62mm_Horizontal
SW1: SW_DIP_x02; SW_DIP_SPSTx02_Slide_9.78x7.26mm_W7.62mm_P2.54mm
U1: 27C512; DIP-28_W15.24mm_Socket
U3: 74HC00; DIP-14_W7.62mm_Socket

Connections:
+5V: C2.1, C5.1, J1.1b, SW1.1, SW1.2, U1.28 (VCC), U3.14 (VCC)
A0: J1.6a, U1.10 (A0)
A1: J1.6b, U1.9 (A1)
A2: J1.7a, U1.8 (A2)
A3: J1.7b, U1.7 (A3)
A4: J1.8a, U1.6 (A4)
A5: J1.8b, U1.5 (A5)
A6: J1.9a, U1.4 (A6)
A7: J1.9b, U1.3 (A7)
A8: J1.10a, U1.25 (A8)
A9: J1.10b, U1.24 (A9)
A10: J1.11a, U1.21 (A10)
A11: J1.11b, U1.23 (A11)
A12: U1.2 (A12), U3.3
A12C: J1.12a, U3.1, U3.2
A13: U1.26 (A13), U3.6
A14: R1.2, SW1.3, U1.27 (A14)
A15: R2.2, SW1.4, U1.1 (A15)
D0: J1.2a, U1.11 (D0)
D1: J1.2b, U1.12 (D1)
D2: J1.3a, U1.13 (D2)
D3: J1.3b, U1.15 (D3)
D4: J1.4a, U1.16 (D4)
D5: J1.4b, U1.17 (D5)
D6: J1.5a, U1.18 (D6)
D7: J1.5b, U1.19 (D7)
GND: C2.2, C5.2, J1.15a, J1.15b, R1.1, R2.1, U1.14 (GND), U3.7 (GND)
unnamed: U3.9, U3.10, U3.11
~CARSEL1: J1.13a, U3.12
~CARSEL2: J1.12b, U3.4, U3.5, U3.13
~CS: U1.20 (~CE), U1.22 (~OE), U3.8
~NMI: J1.1a

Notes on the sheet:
Note that pins ~{CS1} and ~{CS2} are incorrectly placed in the Field Support Manual. Also see this link: https://www.circuitsonline.net/forum/view/message/2120842#2120842
Cartridge edge connection
Flash chip
Address line decoding
The lower 12 bits are specified by the P2000T (and the decoder circuit), the upper 2 bits can be set by the user to select the rom.
Address selection

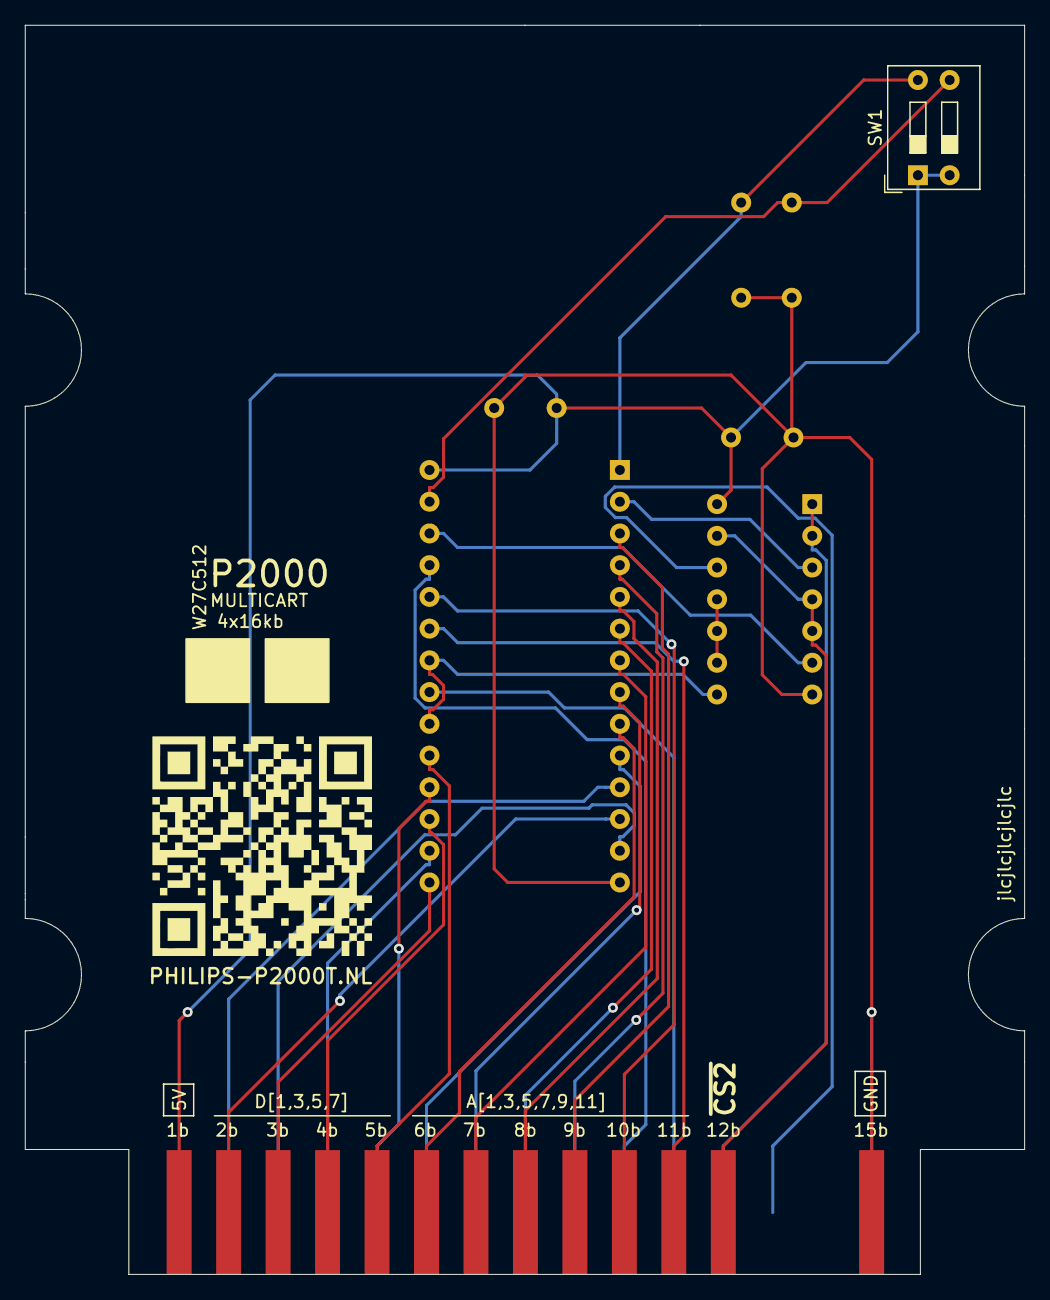
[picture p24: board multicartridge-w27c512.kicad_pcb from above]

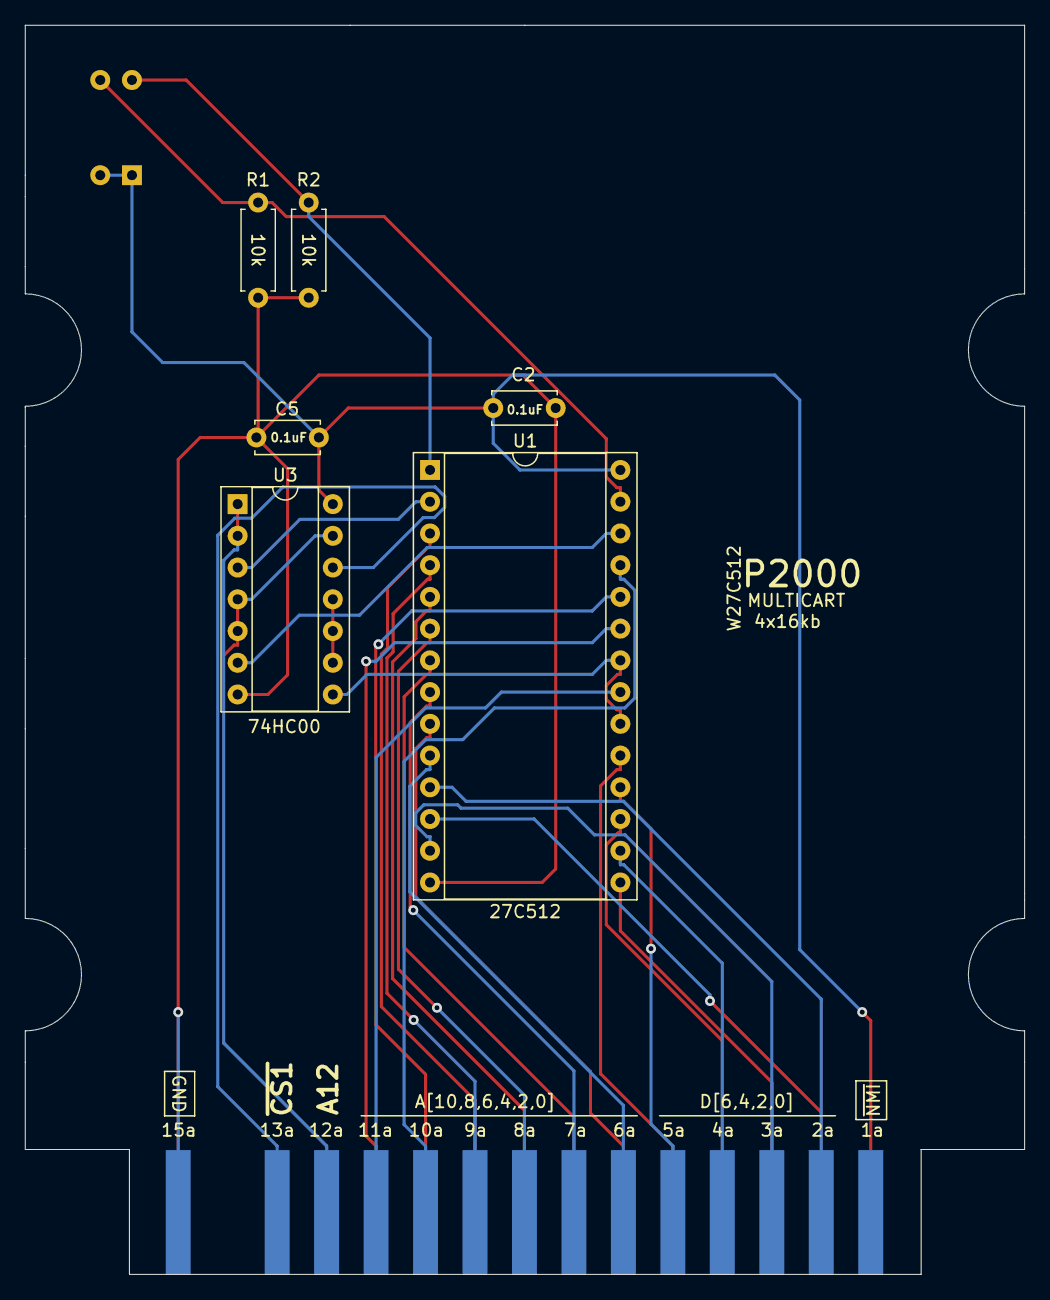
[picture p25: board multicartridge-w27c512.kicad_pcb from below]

Board: 2 copper layers, 80.0 x 100.0 mm, 8 parts (7 on the bottom side), 31 nets.

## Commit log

2023-08-06 Adding cases for multicartridge
    [p2000t-multicartridge-top.stl, p2000t_multicartridge_bottom_mouse_ears.stl, p2000t_multicartridge_top.stl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]
2023-08-06 Adding P2000T-multicartridge-plcc32
    [p2000t-multicartridge-B_Cu.gbr, p2000t-multicartridge-B_Mask.gbr, p2000t-multicartridge-B_Paste.gbr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]
2023-08-06 Adding ZIF cartridge
    [p2000t-multicartridge-zif-B_Cu.gbr, p2000t-multicartridge-zif-B_Mask.gbr, p2000t-multicartridge-zif-B_Paste.gbr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]
2023-08-06 Adding DIP switch plate
    [dipswitch-plate-B_Cu.gbr, dipswitch-plate-B_Mask.gbr, dipswitch-plate-B_Paste.gbr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]
2023-09-10 Removing label
    [p2000t-multicartridge.kicad_pcb]
2023-09-10 Fixing cases
    [p2000t-multicartridge-top.stl, p2000t_multicartridge_bottom.stl]
2023-09-14 Initial commit Multicartridge SMD
    [p2000t-multicartridge-smd-B_Cu.gbr, p2000t-multicartridge-smd-B_Mask.gbr, p2000t-multicartridge-smd-B_Paste.gbr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]
2023-09-14 Removing old GERBERS
    [p2000t-multicartridge-smd-B_Cu.gbr, p2000t-multicartridge-smd-B_Mask.gbr, p2000t-multicartridge-smd-B_Paste.gbr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]
2023-09-15 Completing PCB
    [p2000t-multicartridge-smd-B_Cu.gbr, p2000t-multicartridge-smd-B_Mask.gbr, p2000t-multicartridge-smd-B_Paste.gbr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]
2023-09-15 Updating schematic
    [p2000t-multicartridge-smd.kicad_sch]
2023-09-23 Adding cases
    [p2000t-multicartridge-smd-B_Cu.gbr, p2000t-multicartridge-smd-B_Mask.gbr, p2000t-multicartridge-smd-B_Paste.gbr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]
2023-09-24 Adding labels to cartridges
    [p2000t-smd-bottom.stl, p2000t-smd-top.stl, p2000t_cartridge_zif_bottom.stl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]
2024-01-02 Revision of ZIF cartridge
    [p2000t-multicartridge-zif-B_Cu.gbr, p2000t-multicartridge-zif-B_Mask.gbr, p2000t-multicartridge-zif-B_Paste.gbr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]
2024-01-12 Adding revised top case
    [p2000t_cartridge_zif_top.stl]
2024-01-13 Revising front case
    [p2000t_cartridge_zif_top.stl]
2024-03-01 Multicartridge w27c512 (#2)
    * Initial commit P2000T cartridge using W27C512 chips
    * Adding cases
    * Tuning access hole
    * Updating GERBERS
    * Expanding README.md
    [multicartridge-w27c512-B_Cu.gbr, multicartridge-w27c512-B_Mask.gbr, multicartridge-w27c512-B_Paste.gbr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]
2024-04-03 Tuning lay-out multirom cartridge
    [p2000t-multicartridge-B_Cu.gbr, p2000t-multicartridge-B_Mask.gbr, p2000t-multicartridge-B_Paste.gbr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]
2024-04-16 Updating case design
    [multicartridge_w27c512_bottom.stl, multicartridge_w27c512_top.stl, p2000t_multicartridge_bottom.stl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]
2024-04-16 Expanding README.md
    [p2000t-multicartridge-smd.kicad_pcb, p2000t-multicartridge-smd.kicad_sch]
2024-04-26 Adding 4mm inserts for W27C512
    [multicartridge_w27c512_top_4mm_inserts.stl]
2024-04-27 Revising case
    [multicartridge_w27c512_bottom.stl, multicartridge_w27c512_top.stl]
2024-06-15 Creating extra cases
    [multicartridge-w27c512.kicad_sch, multicartridge_w27c512_bottom.stl, multicartridge_w27c512_top_4mm_inserts.stl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]
2024-07-28 Revising bottom enclosure multirom cartridge
    [p2000t_multicartridge-bottom.stl]
2024-10-12 Improving bottom plate
    [p2000t_multicartridge-bottom.stl]
2024-12-20 Modyfing cases
    [p2000t_multicartridge-top-inserts-38.stl, p2000t_multicartridge-top.stl]
2025-01-02 Adding STL files and game ROMs
    [flexconnector-B_Cu.gbr, flexconnector-B_Mask.gbr, flexconnector-B_Paste.gbr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]
2025-01-02 Adding FLEX PCB
    [flexconnector-B_Cu.gbr, flexconnector-B_Mask.gbr, flexconnector-B_Paste.gbr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]
2025-01-06 Adding 8x16kb cartridge for SST39SF010
    [multicartridge-sst39sf010-B_Cu.gbr, multicartridge-sst39sf010-B_Mask.gbr, multicartridge-sst39sf010-B_Paste.gbr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]
2025-01-06 Improving case
    [p2000t_multicartridge-bottom.stl, p2000t_multicartridge-label-03-bottom.stl, p2000t_multicartridge-label-03-top.stl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]
2025-01-06 Tuning flexcable
    [flexconnector-B_Cu.gbr, flexconnector-B_Mask.gbr, flexconnector-B_Paste.gbr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]
2025-01-07 Adding PCB and rewriting README.md
    [dipswitch-plate-B_Cu.gbr, dipswitch-plate-B_Mask.gbr, dipswitch-plate-B_Paste.gbr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]
2025-01-15 Refining games cartridge
    [multicartridge-sst39sf010-B_Cu.gbr, multicartridge-sst39sf010-B_Mask.gbr, multicartridge-sst39sf010-B_Paste.gbr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]
2025-01-25 Updating Case
    [p2000t_gamecartridge_w27c512_bottom.stl, p2000t_gamecartridge_w27c512_label_bottom.stl, p2000t_gamecartridge_w27c512_label_top.stl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]
2026-09-05 Adding hardware implementation for a programmable 32u4 based cartridge (#3)
    * Initial commit new design
    * Revising design
    * Adding 32u4-type programmable multirom cartridge
    * Initial commit firmware
    * Adding bootloader source and expanding firmware functionality
    * Refactoring and removing sources to different repository
    [bottom-bare.stl, multicartridge-smd-32u4-front-dipswitch.kicad_pcb, multicartridge-smd-32u4-front-dipswitch.kicad_sch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]
2026-09-05 Adding multicolor enclosures
    [bottom.stl, label-bottom.stl, label-top.stl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]
2026-10-24 Revising enclosure
